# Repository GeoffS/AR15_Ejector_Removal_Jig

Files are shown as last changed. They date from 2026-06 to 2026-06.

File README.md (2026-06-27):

# AR15 Ejector-Removal Jig

## Introduction
This design is for an extremely simple and easy-to-print jig to compress the
ejector-spring in an AR-15 bolt so the roll-pin can be easily driven out
with a punch.

There are two versions ("left" and "right") that allow you to drive the pin out from
either side of the bolt.

## Printing:
Slicer setting do not seem to be be to critical. 

Thesee are probably a bit on the "light" side, but I used:
* Polymaker Polylight PLA
* 0.4mm nozzle.
* Two perimeters.
* Three botom layers and five top layers.
* The default Banbu slicer perimeter widths (~0.42mm) and layer height (0.2mm).
* 15% gyroid infill.

## Assembly
I requires a couple of pieces of hardware to complete:

1) A 20mm long M8 socket-head bolt to insert into the cam-pin hole. This prevents the bolt from turning when the pin is driven out.
2) An aT Least 25mm long M8 bolt to depress the ejector pin.
3) A 12mm long cut-off .223/5.56/300 BLK cartridge case.
4) An M8 nut.

I had to round over and polish the end of the M8 bolt that pushes on the 
cut-off cartridge so it would not catch on the cartridge interior.

I also smoothed and polished the end of the cam-pin bolt so it would fit into the cam-pin
hole.

The nut is pulled into the recess.

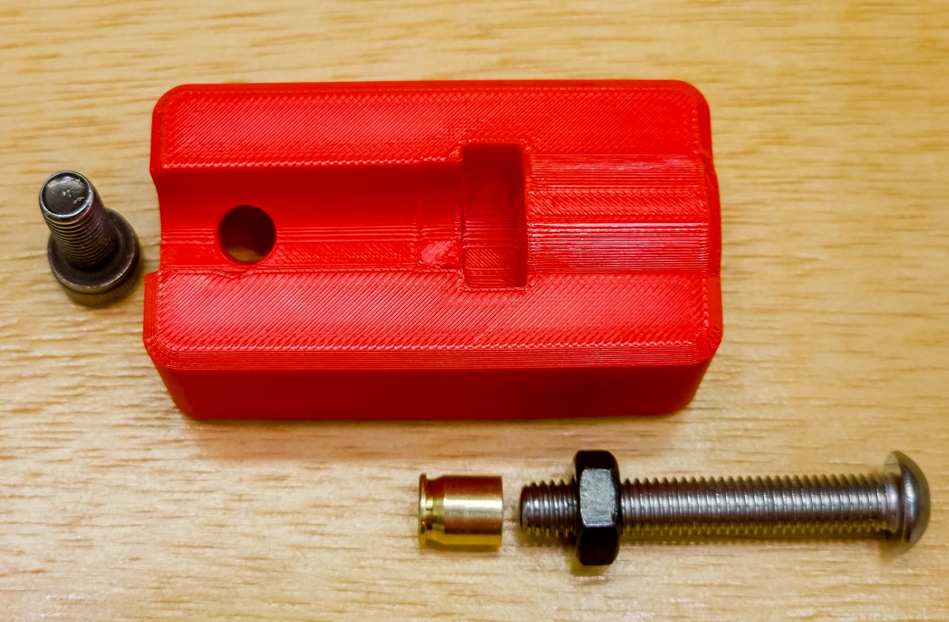
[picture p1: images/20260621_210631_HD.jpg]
Pieces

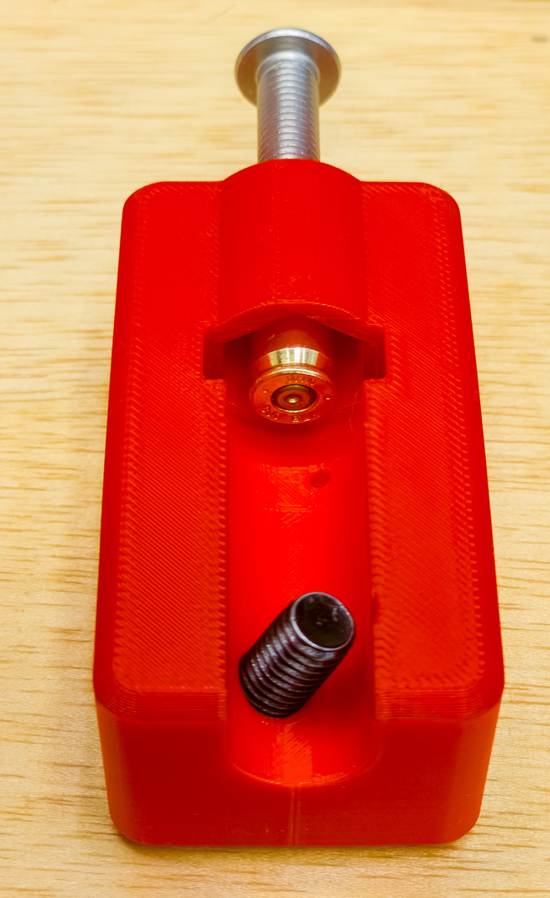
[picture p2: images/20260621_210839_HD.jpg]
Assembled, end-view

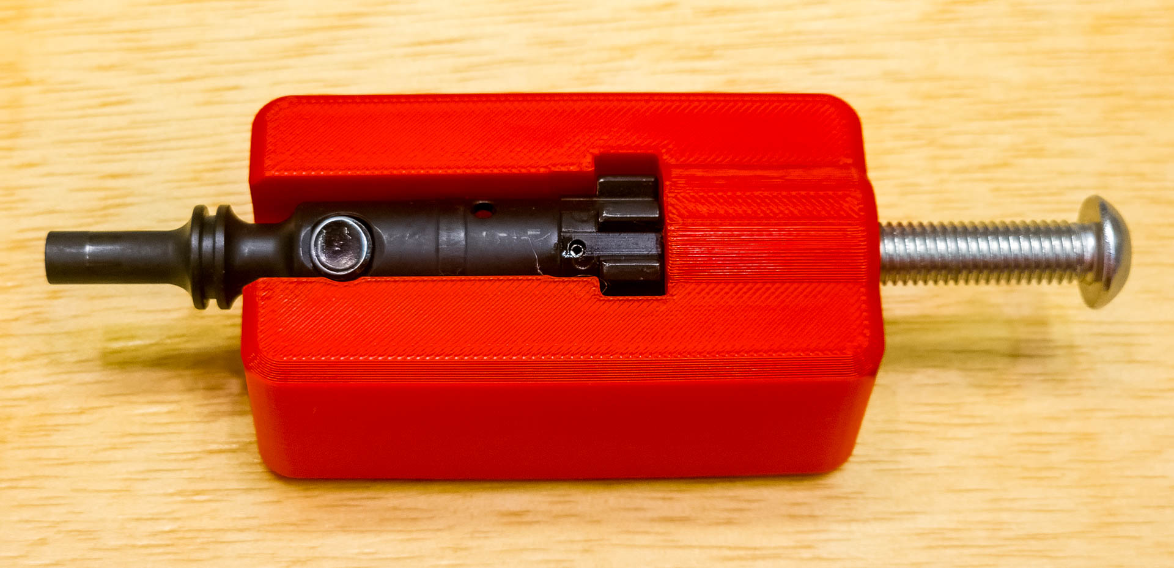
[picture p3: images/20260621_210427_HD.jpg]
Bolt in-plase


## Building the STL files from source:

In order to build these designs from the [OpenScad](https://openscad.org) source, you will need a few things:

1. [Python 3](https://www.python.org) (the version should not be critical - I am currently using 3.10.7)

1. Download an OpenSCAD build later than **OpenSCAD-2025.12.09** </br>
At the time of writing, the [OpenSCAD official release](https://openscad.org/downloads.html) is much too old, and you have to 
get one of the [nightly-builds](https://openscad.org/downloads.html#snapshots) (which have been very reiliable for years - I woud recommend the most recent one).

2. Note where the `openscad.exe` file in installed. </br>
I usually grab the `zip` installation and unzip it into a directory like `C:\tools\OpenSCAD-2025.12.09-x86-64` (when I'm using Windows).

2. Clone/unzip my OpenSCAD library beside this repository (i.e. in the same directtory)
[https://github.com/GeoffS/OpenSCAD_Lib](https://github.com/GeoffS/OpenSCAD_Lib)

2. Open a shell, and navigate to the directory where this repo is located.

1. Run the command: </br>
(the path after the `-osc` option is the one you noted above) </br>
`python ..\OpenSCAD_Lib\makeStls.py .\AR15_Ejector_Removal_Jig.scad -osc C:\tools\OpenSCAD-2025.12.09-x86-64\openscad.exe`

If all went well you should see these lines at the end of the output:
```
All commands completed with no errors.
Done!
```

You should also get three `.stl` files in the parent directory:
* AR15_Ejector_Removal_Jig LeftJig.stl
* AR15_Ejector_Removal_Jig RightJig.stl
* AR15_Ejector_Removal_Jig CartridgeInsert.stl

Ignore the last one; it's a work-in-progress to use an M6 bolt.

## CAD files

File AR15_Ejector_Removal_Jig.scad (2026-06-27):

// Copyright 2026 - Geoff SObering - All Rights Reserved
// Licensed under the GNU GENERAL PUBLIC LICENSE, Version 3

include <../OpenSCAD_Lib/MakeInclude.scad>
include <../OpenSCAD_Lib/chamferedCylinders.scad>

firstLayerHeight = 0.2;
layerHeight = 0.2;

makeRightJig = false;
makeLeftJig = false;
makeCartridgeInsert = false;

boltLugsOD = 19; //2*0.370  * mm;
boltLugsID = 14; //2*0.265 * mm;
boltLugsY = 7.5; //0.280 * mm;
boldRearOD = 13.5;

camPinCtrY = 1.431 * mm;
camPinAngle = 45/2;
campPinOD = 8.1;

ejectorPinOffsetX = 0.113 * mm;
ejectorPinOffsetY = 0.372 * mm;
ejectorPinRecesssDia = 2*0.032*mm + 1;

boltY = 48; //2 * mm;

cartrdigeBaseY = 12;
nutY = 7;

wallX = 10;
wallY = 6 + nutY + cartrdigeBaseY;
wallZ = 12; //firstLayerHeight + 2*layerHeight;
aboveBoltZ = -2;

jigX = boltLugsOD + 2*wallX;
jigY = wallY + boltY;
jigZ = boltLugsOD + wallZ + aboveBoltZ;

jigCornerDiaXY = 10;
jigCZ = 2;

module rightJig()
{
	difference() 
	{
		jigBase();
		ejectorPinHole();
		rightCamPinHole();
	}
}

module leftJig()
{
	difference() 
	{
		jigBase();
		mirror([1,0,0])
		{
			ejectorPinHole();
			rightCamPinHole();
		}
	}
}

module jigBase()
{
	difference()
	{
		// Exterior:
		union()
		{
			// Main rightJig body:
			translate([0, jigY/2-wallY, 0]) hull() doubleX() doubleY() 
				translate([jigX/2-jigCornerDiaXY/2, jigY/2-jigCornerDiaXY/2,-wallZ-boltLugsOD/2]) 
					simpleChamferedCylinderDoubleEnded(d=jigCornerDiaXY, h=jigZ, cz=jigCZ);
			// Bump for nut recessL
			translate([0, jigCZ, 0]) rotate([90, 0, 0]) simpleChamferedCylinderDoubleEnded(d=22, h=wallY+jigCZ, cz=jigCZ);
		}

		// Bolt Stuff:
		boltRecess()
		{
			// Lugs:
			cylinder(d=boltLugsOD, h=boltLugsY);
			// Bolt body just behind the lugs:
			cylinder(d=boltLugsID, h=13);
			// Bolt body just behind the the extractor pivot:
			tcy([0,0,0], d=boldRearOD, h=100);
		}

		// Ejector pin hole:
		

		// Screw:
		hull()
		{
			d = 8.2;
			rotate([-90,0,0]) tcy([0,0,-50], d=d, h=100);
			x = d * 0.3;
			tcu([-x/2, -30, 0], [x, 100, d/2]);
		}

		// Nut recess:
		rotate([-90,0,0]) rotate([0,0,30]) translate([0,0,-cartrdigeBaseY]) 
		{
			tcy([0,0,-nutY], d=15.8+0.2, h=25, $fn=6);
			hull()
			{
				tcy([0,0,0], d=15.8+0.2, h=1, $fn=6);
				tcy([0,0,cartrdigeBaseY], d=18, h=1, $fn=6);
			}
		}
		
		// Cam-Pin hole:
		
	}
}

module ejectorPinHole()
{
	translate([-ejectorPinOffsetX, ejectorPinOffsetY, 0]) tcy([0,0,-50], d=ejectorPinRecesssDia, h=100);
}

module rightCamPinHole()
{
	translate([0,camPinCtrY,0]) rotate([0,-camPinAngle,0]) 
	{
		tcy([0,0,-50], d=campPinOD, h=100);
		tcy([0,0,-100-boldRearOD/2-5.5], d=14, h=100);
	}
}

module boltRecess()
{
	echo(str("Bolt recess(", $children, ")"));

	rotate([-90, 0, 0]) for(i = [0, 1, $children-1])
	{
		echo(str("Bolt recess()  i = ", i));

		hull()
		{
			children(i);
			translate([0,-100,0]) children(i);
		}
	}
}

module m6ScrewCartridgeInsert()
{
	difference()
	{
		union()
		{
			d1 = 7.4;
			h = 6.5;
			cz = firstLayerHeight+2*layerHeight;
			simpleChamferedCylinderDoubleEnded(d = d1, h = h, cz = cz);
			translate([0,0,cz]) cylinder(d1=7.4, d2=7.9, h=h-cz);
		}
		
		tcy([0,0,firstLayerHeight+4*layerHeight], d=6.1, h=100);
	}
}

module clip(d=0)
{
	// tc([-200, -400-d, -10], 400);
	// tcu([0-d, -200, -200], 400);
	// tcu([-200, camPinCtrY-d, -200], 400);
}

if(developmentRender)
{
	display() rightJig();
	display() translate([-60,0,0]) leftJig();
	// display() m6ScrewCartridgeInsert();
}
else
{
	if(makeRightJig) rightJig();
	if(makeLeftJig) leftJig();
	if(makeCartridgeInsert) m6ScrewCartridgeInsert();
}

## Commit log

2026-06-20 Created cartridgeInsert() and fixed extension.
    [AR15_Ejector_Removal_Jig.scad]
2026-06-20 First cartridgeInsert() print.
    [AR15_Ejector_Removal_Jig.scad]
2026-06-21 Initial exterior.
    [AR15_Ejector_Removal_Jig.scad]
2026-06-21 Test print.
    [AR15_Ejector_Removal_Jig.scad]
2026-06-21 Now, a test print...
    [AR15_Ejector_Removal_Jig.scad]
2026-06-21 Added taper to nut recess for easier installation.
    [AR15_Ejector_Removal_Jig.scad]
2026-06-21 Added hole for the cam-pin.
    [AR15_Ejector_Removal_Jig.scad]
2026-06-21 More y-length.
    [AR15_Ejector_Removal_Jig.scad]
2026-06-21 Reduced jig height. Added extra over nut.
    [AR15_Ejector_Removal_Jig.scad]
2026-06-21 Added the ejector-pin recess.
    [AR15_Ejector_Removal_Jig.scad]
2026-06-22 Removed "mm" definition since it's in OpenSCAD_Lib/MakeInclude.scad now.
    [AR15_Ejector_Removal_Jig.scad]
2026-06-27 Renamed m6ScrewCartridgeInsert()
    [AR15_Ejector_Removal_Jig.scad]
2026-06-27 Renamed rightJig()
    [AR15_Ejector_Removal_Jig.scad]
2026-06-27 Added leftJig()
    [AR15_Ejector_Removal_Jig.scad]
2026-06-27 Added GPL header in source file.
    [AR15_Ejector_Removal_Jig.scad]
2026-06-27 A couple of last additions to the README.md
